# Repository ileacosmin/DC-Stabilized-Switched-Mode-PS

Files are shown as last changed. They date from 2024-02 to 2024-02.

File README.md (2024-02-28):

# DC Stabilized Switched Mode Power Supply

## Description
This project involves the design and implementation of a switched-mode power supply (SMPS) aimed at stabilizing a DC output voltage. The system utilizes a transformer, a full-wave rectifier, and a buck converter controlled through the pulse-width modulation (PWM) method.

## Features
- Utilizes KiCad for designing the electrical schematic.
- Employs MATLAB for computing the controllers and simulating the performance against certain disturbances.
- Switched-mode operation for efficiency and stability.
- Pulse-width modulation (PWM) control for precise regulation of output voltage.
- Full-wave rectification for converting AC input to DC.

## Electrical Scheme
schema electrica_page-0001

<!-- Insert snippet of the electrical schematic here -->

## Design Process
1. **Schematic Design**: Utilize KiCad to design the electrical schematic, including components such as the transformer, rectifier, and buck converter.
2. **Controller Design**: Use MATLAB to compute the controllers required for stable operation of the buck converter. This includes determining the PWM signals for regulating the output voltage.
3. **Simulation**: Simulate the performance of the SMPS against various disturbances using MATLAB to ensure stability, efficiency, and proper regulation of the output voltage.
4. **Implementation**: Fabricate the designed circuit and implement the controllers to create the physical SMPS.

## Conclusion
The DC stabilized switched-mode power supply provides a reliable and efficient solution for stabilizing DC output voltage. By leveraging KiCad for schematic design and MATLAB for controller computation and simulation, the project ensures optimal performance and stability under varying operating conditions.

## References
- [KiCad](https://kicad-pcb.org/)
- [MATLAB](https://www.mathworks.com/products/matlab.html)

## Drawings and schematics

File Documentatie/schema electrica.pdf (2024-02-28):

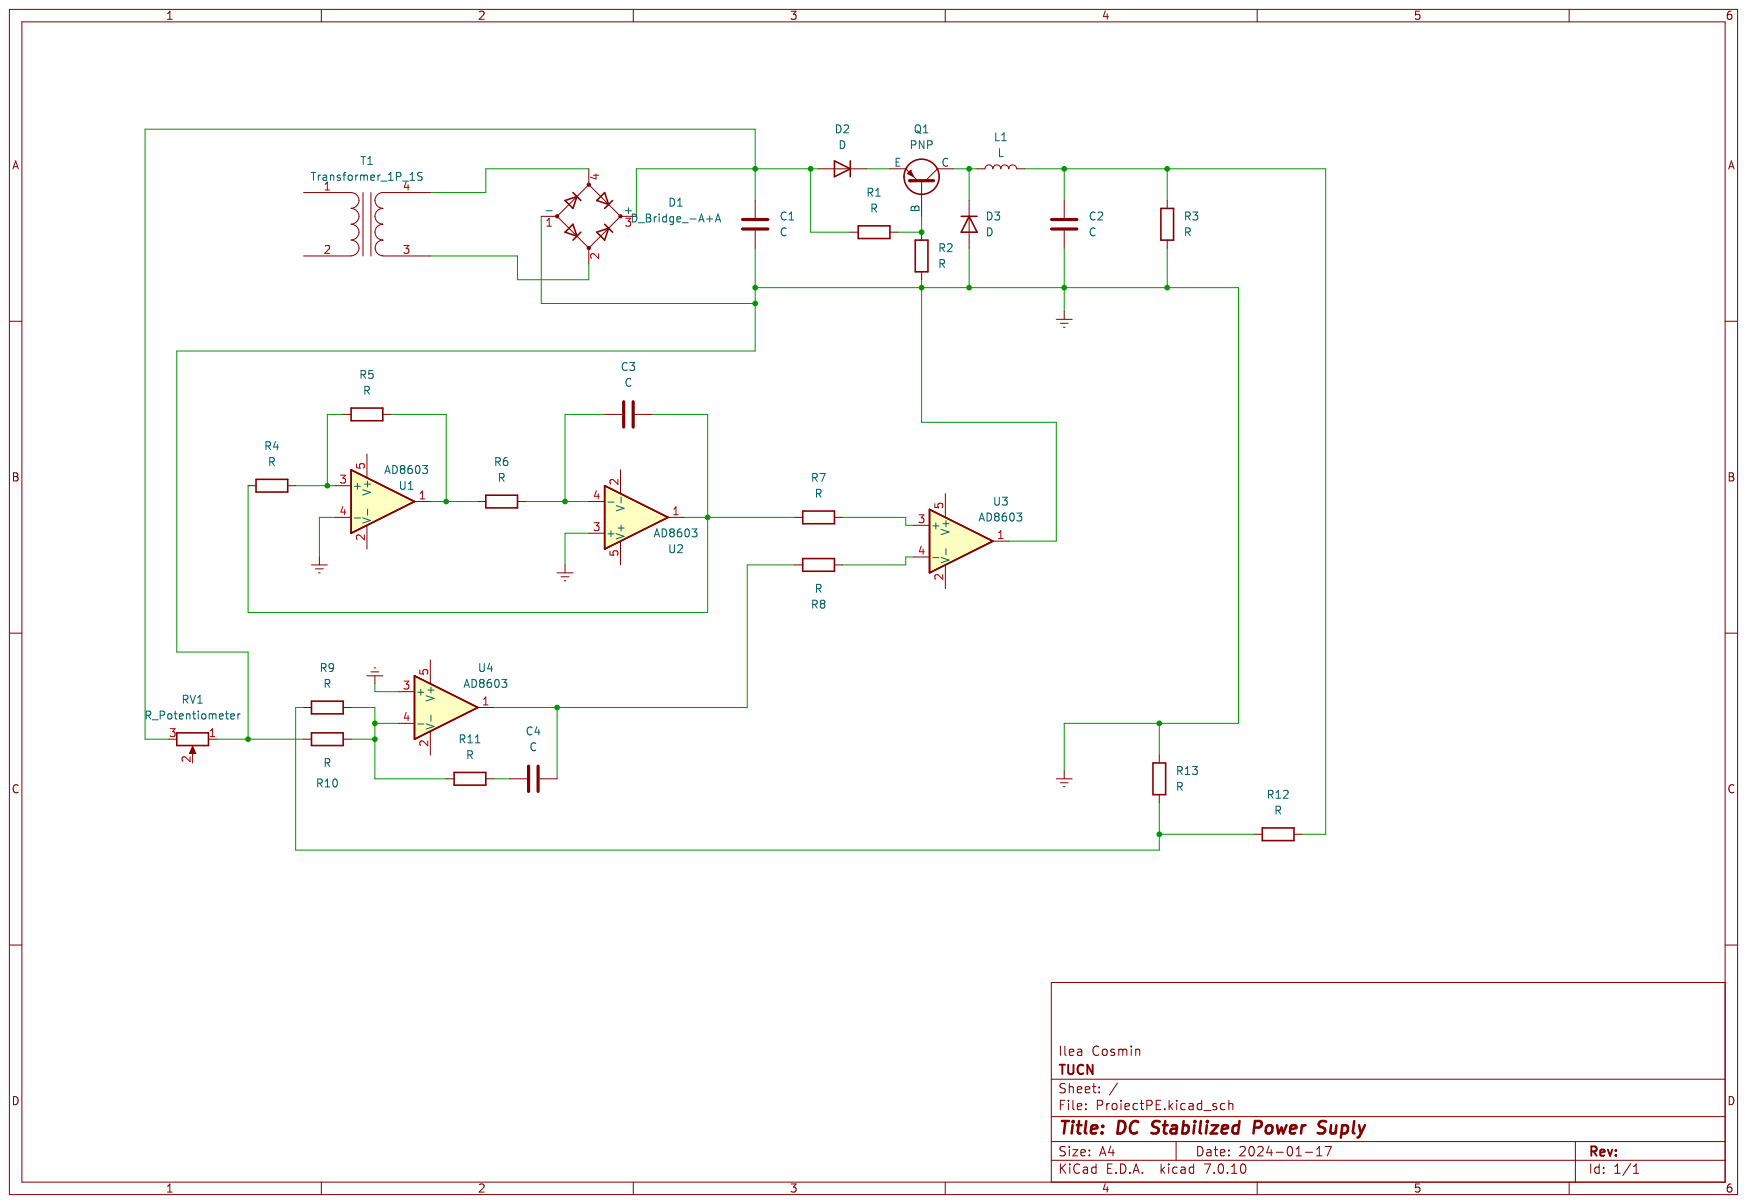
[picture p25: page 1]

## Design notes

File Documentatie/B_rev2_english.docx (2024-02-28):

B. DESIGN OF CONTROLLED DC power supplies

In section (A) was designed one unstabilized DC power supply using smoothing capacitor as presented in figure 6:

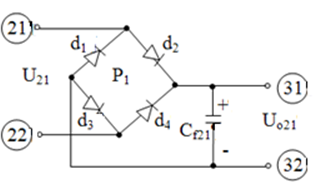
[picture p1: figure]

Figure 6. Uncontrolled rectifier, unstabilized

The voltage at the terminals (31, 32) is monopolar (+ 31, - 32).

B1. Design of a Step-Down (BUCK) DC power supply using the unstabilized power supply (UO21)

The design of switching mode, stabilized DC power supply (SMPS) cconsists of two steps:

a) The design of a DC- DC Converter which controls the output voltage ( U_(Ost) ), containing a “power” circuit and a duty cycle (µ) control circuit. The DC-DC converter plays the role of an actuator.
b) The design of an appropriate controller able to fulfill certain imposed performance specifications.

The conventional structures for DC-DC step-down converter are given in figure B1.

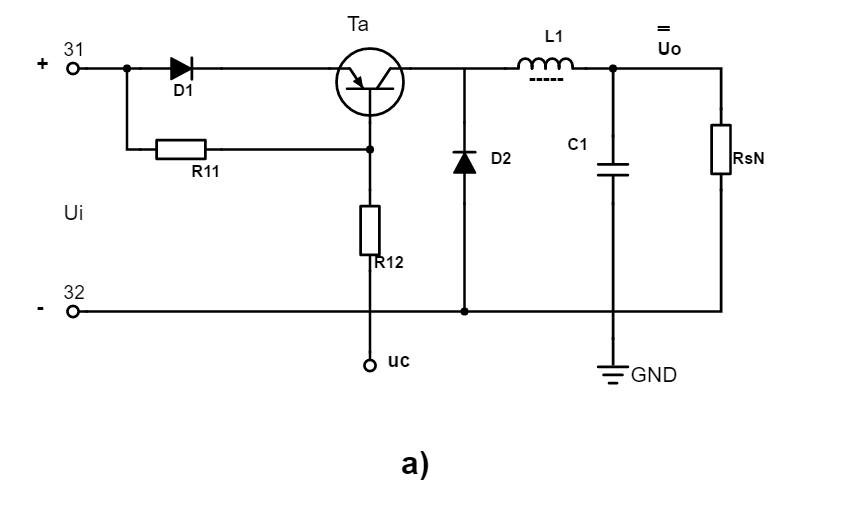
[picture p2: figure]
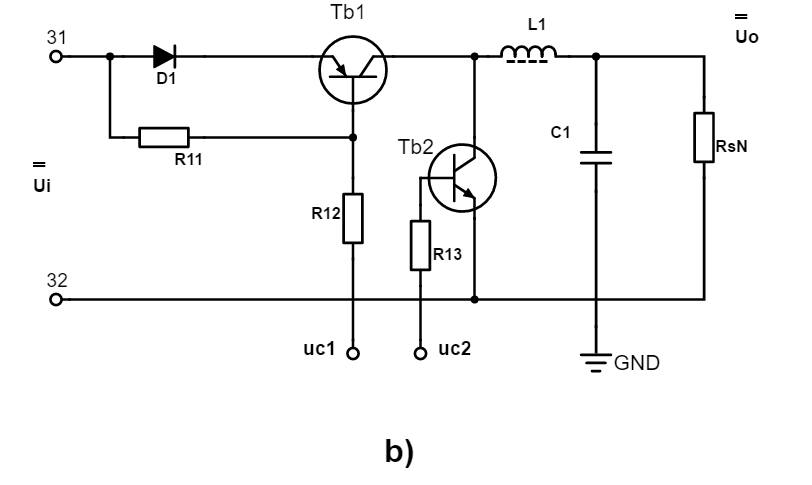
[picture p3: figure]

Figure B1. Switched model step-down DC-DC converter: a) with diode; b) with tranzistors

B1a. Design of the step-down DC-DC converter

A series of initial data are imposed for the design:

1) µ=µo=0.5=constant
2) Nominal load resistor

R_(SN) =(U_2)/(I_2)[Ω]

For which ( U_(2i) , I_(2i) ) are given as initial data for the project.

3) Supply voltage (Ui)

U =k_u ∙E_2 =k_u ∙√2∙U_(2i) [V]

where (ku) is the no load working regime voltage coefficient (A.3.2.3)

4) Maximum supply voltage

(U )_(max) =√2∙U_2

5) Nominal output voltage

V_o =μ_o ∙U ==0,5∙U [V]

6) Nominal load current:

(I_o )_N =(V_o)/(R_S)[A]

7) The current variation limit through the filtering coil:

∆I_L ≅(0,20÷0,30)(I_o )_N [A]

8) The voltage variation limit ( ∆V_O ) due to the alternative component (ripple voltage)

∆V_O ≅(2÷5)%∙V_o [V]

9) Swithching frequency

fc=20[kHz]

Using the presented initial data the elements of the DC-DC converter must be chosen:

1. Knowing that

∆I_L ≅(((U )_(max) -V_o )∙μ_o)/(f_c ∙L)

with ∆I_L ≅(0,20÷0,30)(I_o )_N =(0,20÷0,30)(V_o)/(R_S)

will give the minimum necesarry value of the filtering coil (L):

L≥(((U )_(max) -V_o )∙μ_o)/(f_c ∙∆I_L)[H]

2. Knowing the AC component equilibrium ( ∆I_L , ∆V_O ) results:

∆V_O ≅∆I_L ∙(t_(ON))/C=∆I_L ∙(μ_o ∙T_C)/C=∆I_L ∙(μ_o)/(f_C ∙C)

which gives:

C=(∆I_L ∙μ_o)/(f_C ∙∆V_O)=(0,5∙∆I_L)/(f_C ∙∆V_O)

For the solution presented in figure B1a, the diode (d2) is a Shottky diode which must handle:

- Reverse voltage : U_A ≥1,25∙(U )_(max)
- Rectified current: I_A ≥1,5∙(I_o )_N

considering a safety coefficient of (1,25) for voltage and (1,5) for current.

Diode (d1) is a low frequency diode (rectifier diode) which has to handle the current (IA) previously computed.

Tranzistors (Ta), (Tb1) and (Tb2) for switching frequencies up to 20 (kHz) may be:

- Bipolar tranzistors
- MOSFET tranzistors
- IGBT tranzistors

and must handle:

- A load voltage: U_(tranzistor) =2∙√2∙U_21
- A load current: I_(tranzistor) =1,5∙(I_o )_N

The resistors (R12, R13) can be chosen considering the appropriate control current.

B1b. Design of the control circuit for the step-down DC-DC converter

The structure given in figure 7 corespunde unei prime variante

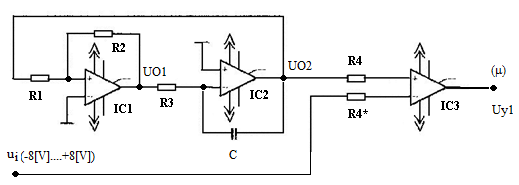
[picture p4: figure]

Figure 7. The structure of the PWM modulator (version)

The operational amplifier (IC1) is used as a Schmidt Trigger and the operational amplifier (IC2) is used as an integrator. (IC3) operational amplifier, with no feedback, is used as a comparator. The considered supply is of (+/- 16 V). In order to generate the triangular wave voltage (UO2) with the amplitude of (A=8V) is necessary that R2=2∙R1. By choosing R2=20[kΩ], will result that R1=10[kΩ].

The switching frequency is given by the following relationship:

f_c =1/(2∙R_3 ∙C)=>R3=0,00021 [Ω]

By choosing at first the capacitor value (C), at an imposed value of the switching frequency, can be computed the value of resistor R3. The comparator (IC3) will generate a rectangular bipolar wave with an amplitude of 16[V], with a duty cycle (μ), controlled by the voltage (ui) and which can be computed by:

μ=(u_i +8)/(2∙A)

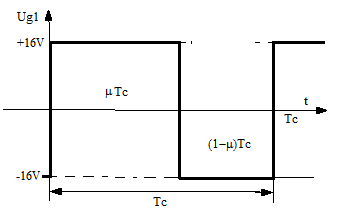
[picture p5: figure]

Figure 8. The evolution of the PWM voltage

The static characteristic of the PWM modulator is given in figure 8.

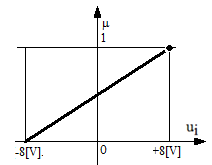
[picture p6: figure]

Figure 9. The variation of the duty cycle (μ)

In the following design steps, the PWM modulator can be considered as an amplification element with an amplification factor of:

K=(∆μ)/(∆u_i)=1/(2A)

The voltage (ui), figure 7 is generated by the controller attached to the circuit.

Observations:

1. The conventional structure of the PWM modulator presented in figure 7 implies a fairly complex practical implementation, beeing the reason why other versions of PWM modulator can be considered and tested.
2. PWM modulator using LM324 integrated circuit (description in Anexa B1)
3. It is recommended to chose a integrated circuit to implement the PWM modulator and include the structure description, the operating mode and application.

Examples of dedicated integrated circuits:

a) TL 494/ TL 594 ("Texas Instruments”)
b) MAX 666 (“Maxim”)
c) LTC 6992-1 (“Linear Technology”)

B1c. The step- down DC-DC converter mathematical model

The structure of the stabilized DC power supply is based on the fixed part presented in figure 10.

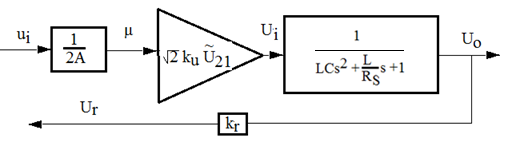
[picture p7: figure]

Figure 10. The fixed part of the switched mode stabilized DC power supply

A resistive voltage divider is considered on the feedback with a factor of kr=0,2.

The reference value of the DC power supply wil be V_0^(*) =μ_0 ∙k_r ∙U_i .

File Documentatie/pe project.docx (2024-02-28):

Technical University of Cluj-Napoca

Faculty of Automation and Computer Science

Project:

DC STABILIZED SWITCHED MODE POWER SUPPLY

C.

The Controllers design

2023-2024

C.1. Controller design

For the project we had to use two different kinds of controllers:

- Proportional
- Proportional-Integral

The transfer function of the fixed part:

H_f (s)=1/(2A)∙√2∙k_u ∙U_2 ∙1/(LCs^2 +L/(R_s)s+1) = 0.6894/(6.49∙10^(-7) ∙s^2 + 0.002596 s + 1)

C.1.1 Proportional Controller Design

Because H_f has two real negative a P controller will not ensure a steady state error ε_(ss) =0 .

We will impose the following performance characteristic for the overshoot σ:

σ=10%

We can use the root locus of the fixed transfer function to tune our controller:

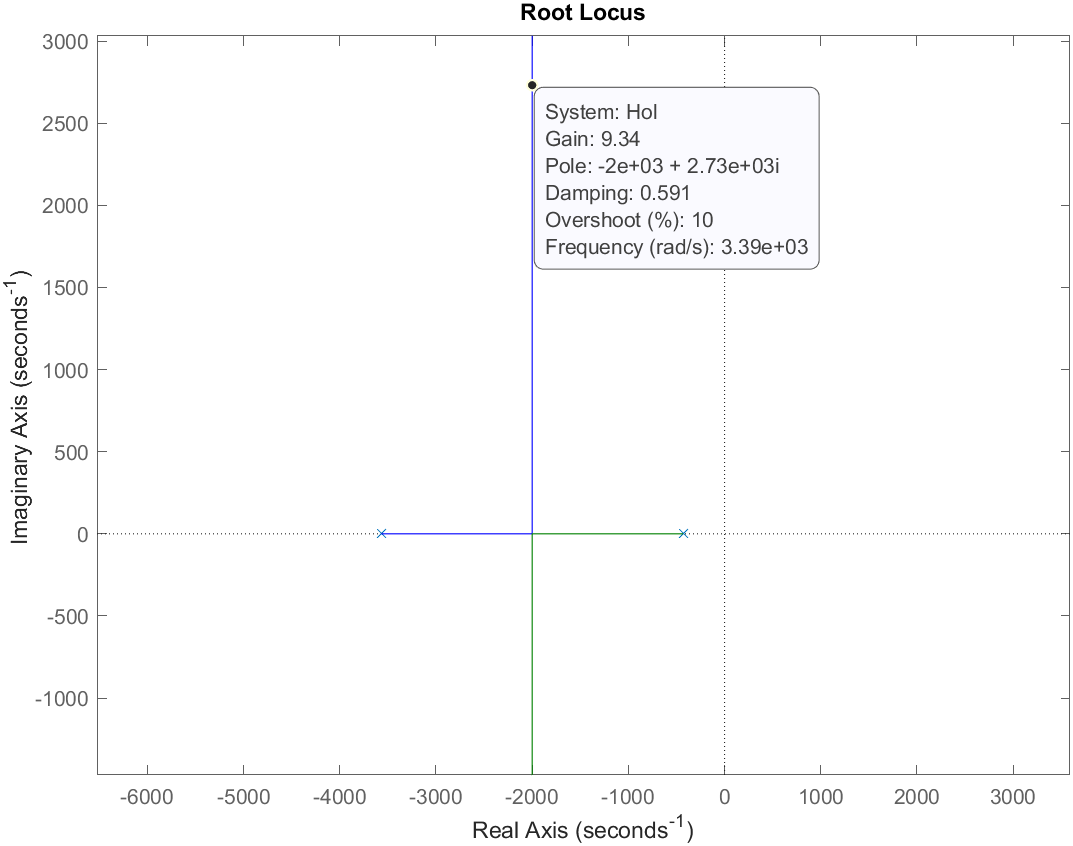
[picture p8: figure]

Therefore the value for kp=9.34

C.1.2 Proportional-Integral Controller Design

We will impose the following performance characteristic for the overshoot σ:

σ=10%

The controller transfer function will be:

H_c (s)=k_p ∙(1+T_i ∙s)/(T_i ∙s)

We will take T_i =1/432 witch is the dominant time constant in our process and we will cancel it.

We can again use the root locus of the fixed transfer function to tune our controller:

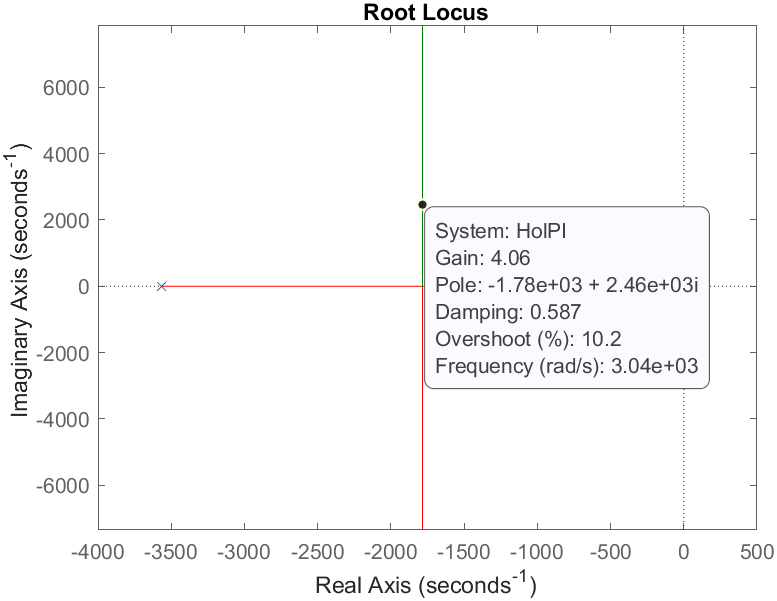
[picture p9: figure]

Therefore the value for kp=4.06 and T_i =1/432 .

Technical University of Cluj-Napoca

Faculty of Automation and Computer Science

Project:

DC STABILIZED SWITCHED MODE POWER SUPPLY

D.

The simulation of the stabilized DC power supply

2023-2024

D.1. Step response

D.1.1 Step response on the P controller:

We have the following simplified mathematical model of the DC power supply:

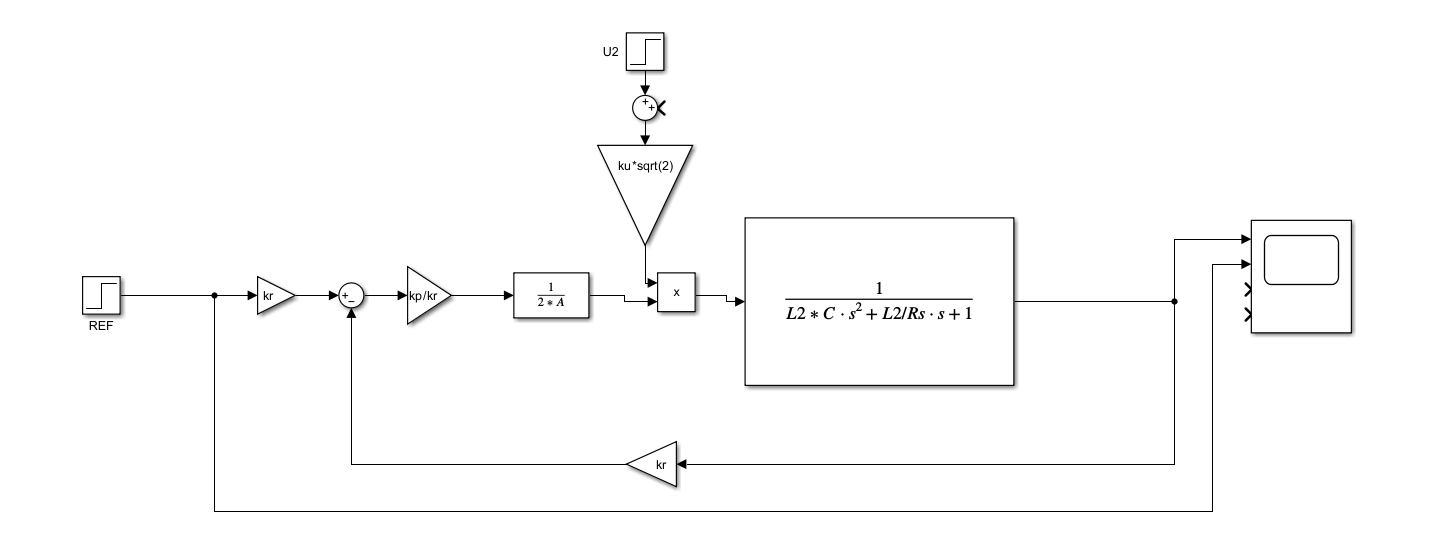
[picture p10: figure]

The reference will be: V_0^(*) =11.03V thus giving the following simulation:

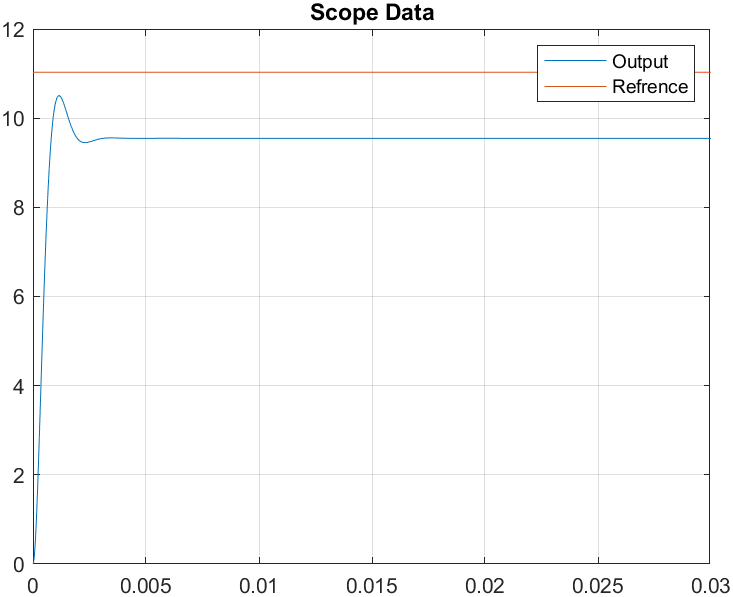
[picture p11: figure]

The output has an overshoot of: σ=10% and a steady state error of: ε_(ssp) =15,71% .

D.1.2 Step response on the PI controller:

The simplified mathematical model of the DC power supply is:

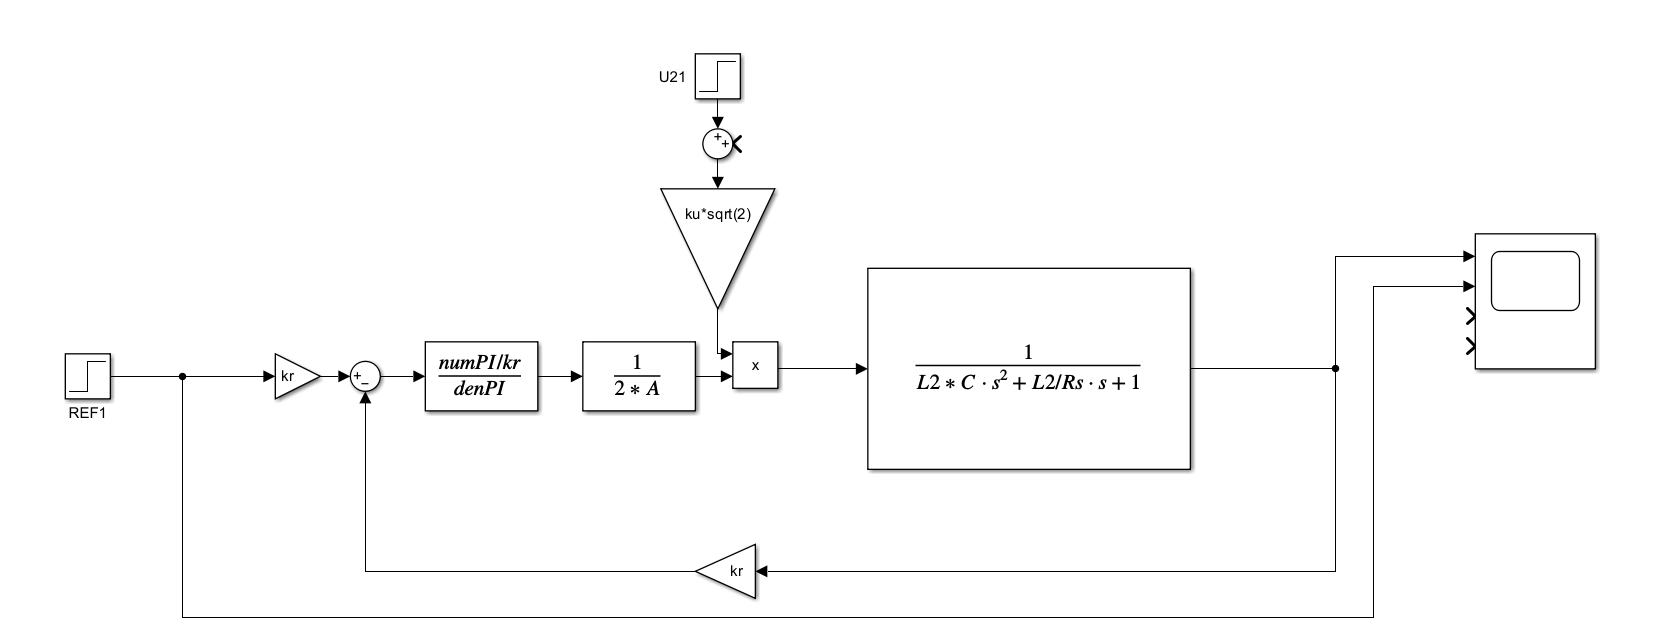
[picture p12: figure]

With the same reference voltage as before we have the following response:

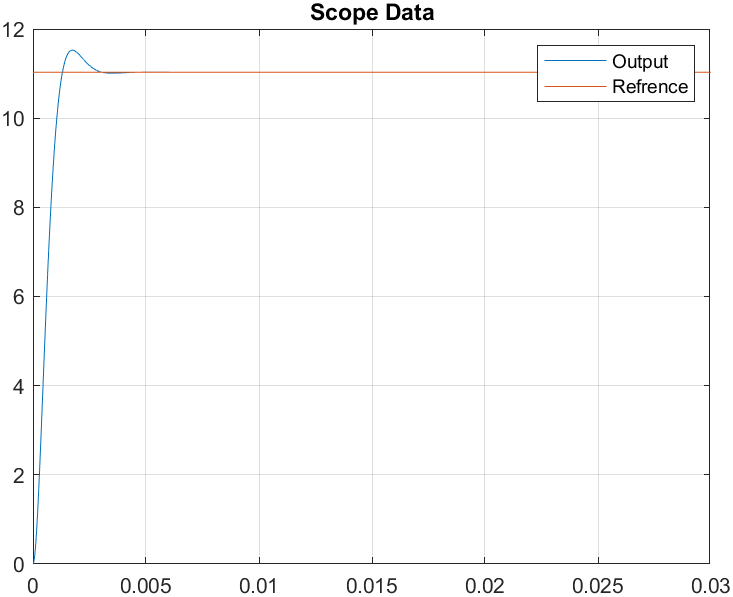
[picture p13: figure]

We see that the overshoot is no more than σ=10% and the steady state error ε_(ssp) =0 .

D.2. Step response with disturbance to the input

D.2.1 Input disturbance on the P controller:

I added a perturbation of 10%∙U2 [V] at the moment in time 0.005 seconds.

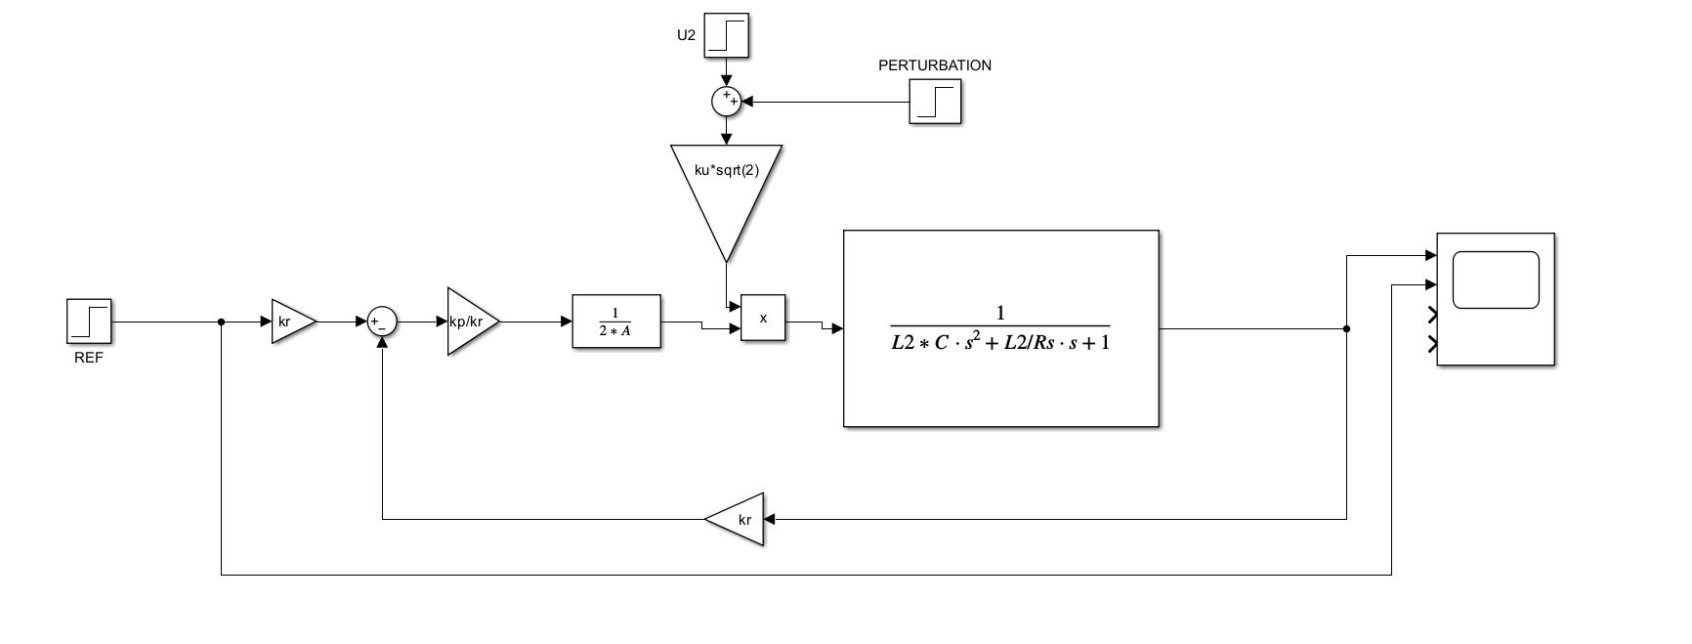
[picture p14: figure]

And this is the result of the simulation:

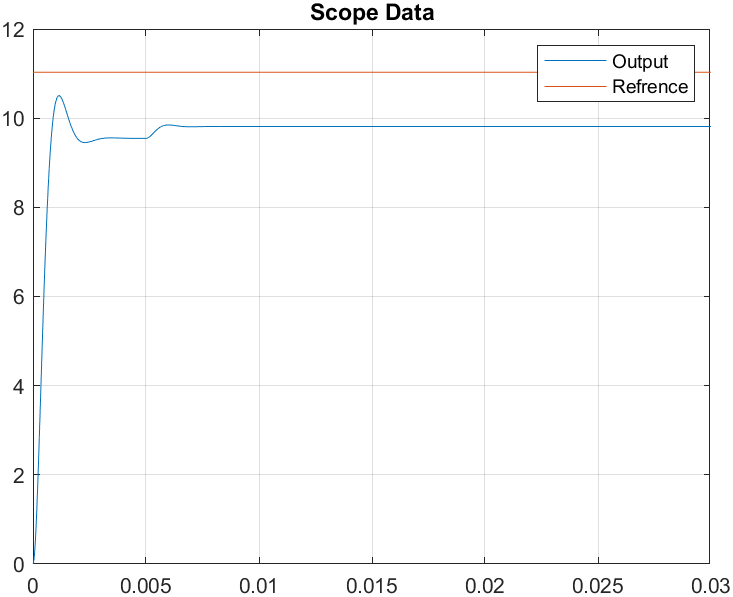
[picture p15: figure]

D.2.2 Input disturbance on the PI controller:

I added a perturbation of -10%∙U2 [V] at the moment in time 0.015 seconds.

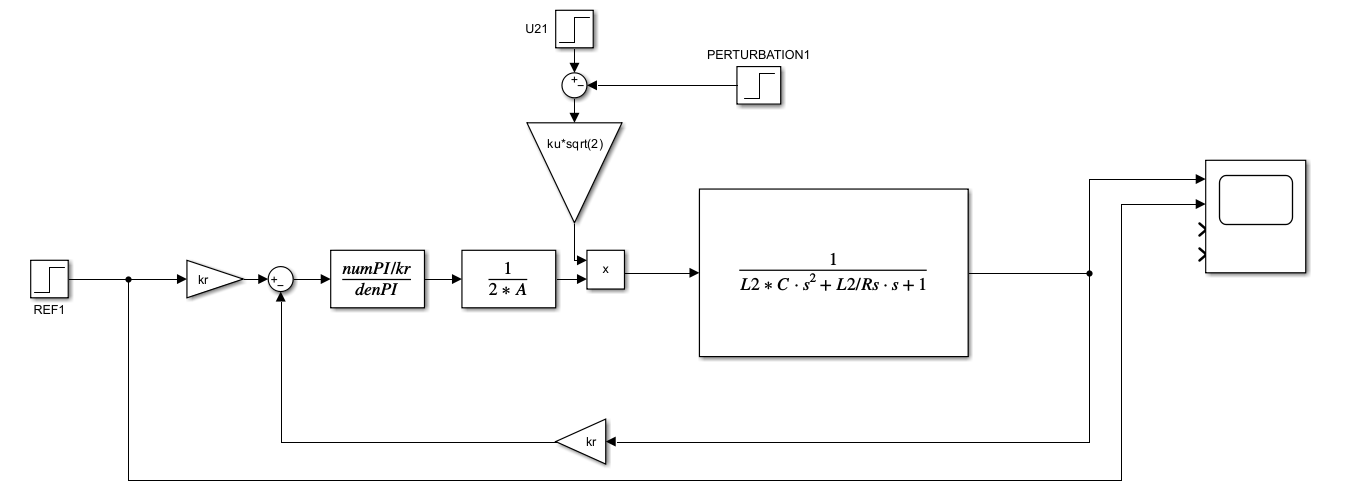
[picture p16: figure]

And this is the result of the simulation:

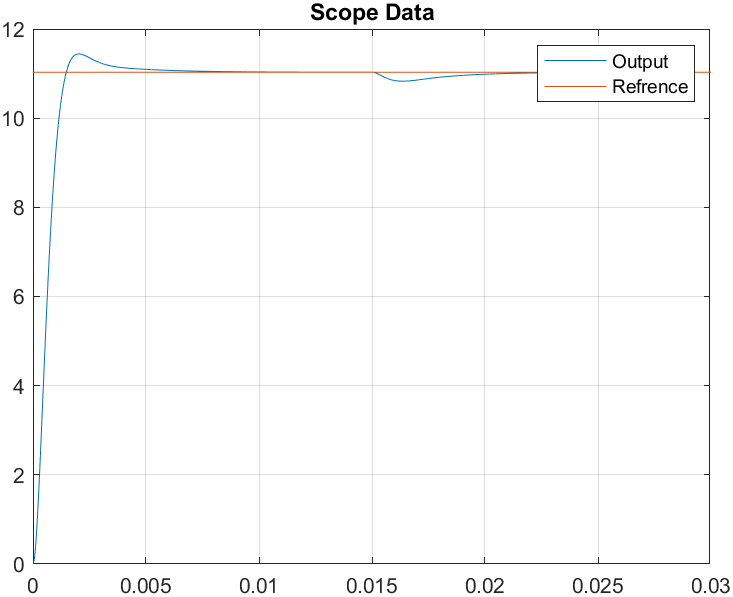
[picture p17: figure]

D.3. Step response with disturbance to the output

D.3.1 Output disturbance on the P controller:

I added a perturbation of -20%∙Rs at the moment in time 0.012 seconds.

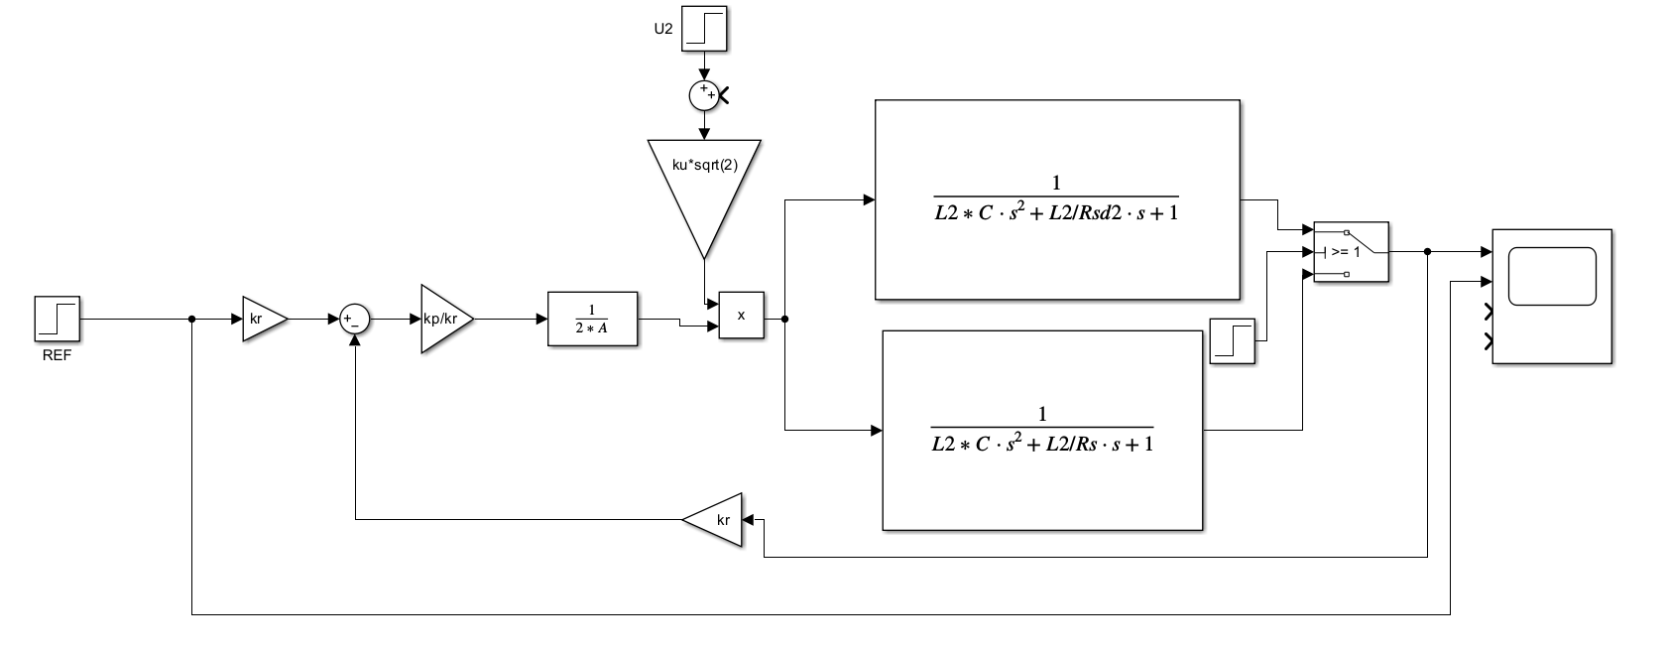
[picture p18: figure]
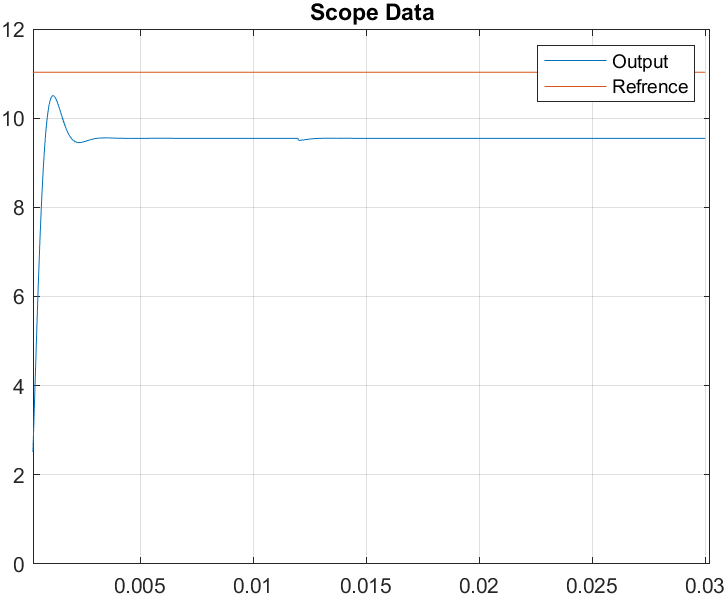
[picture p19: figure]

D.3.2 Output disturbance on the PI controller:

I added a perturbation of -20%∙Rs at the moment in time 0.012 seconds.

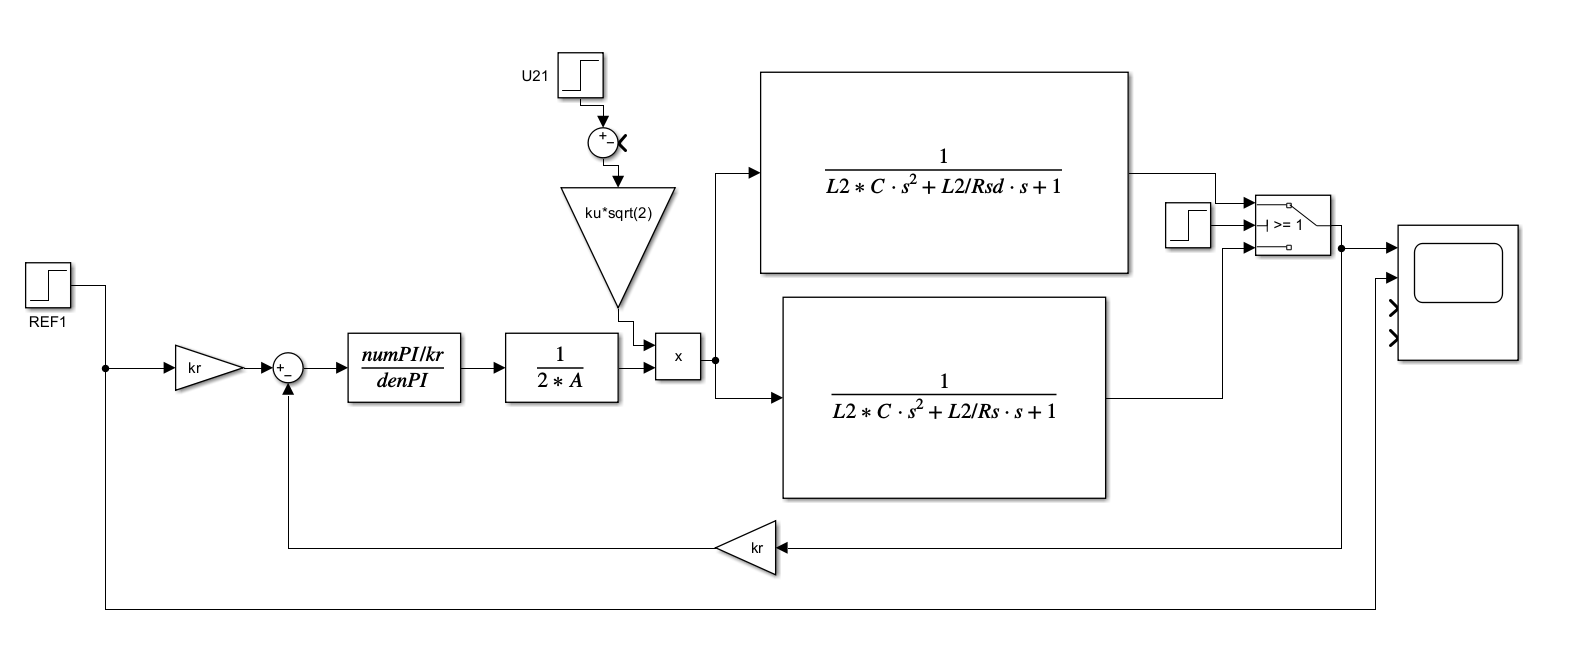
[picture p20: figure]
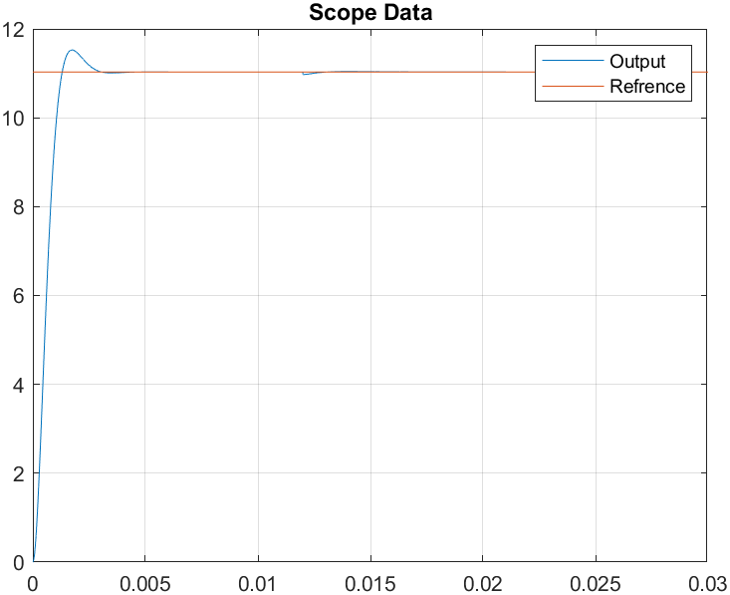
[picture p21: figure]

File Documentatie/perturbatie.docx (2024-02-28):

D.3.1/2 Output disturbance on the P controller (compared):

Used the same disturbance characteristics as in 3.1 but now we see the compared responses.

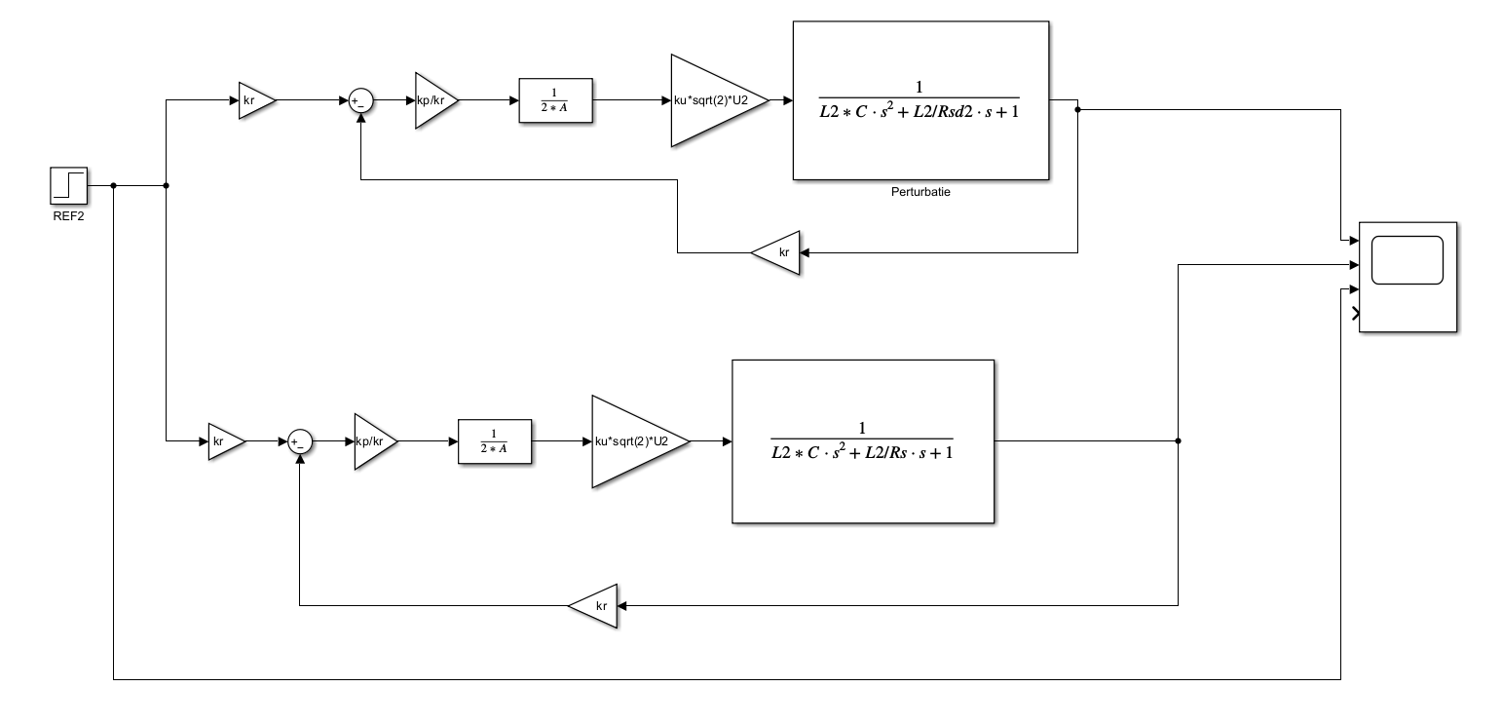
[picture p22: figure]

The P controller shows a lower overshoot.

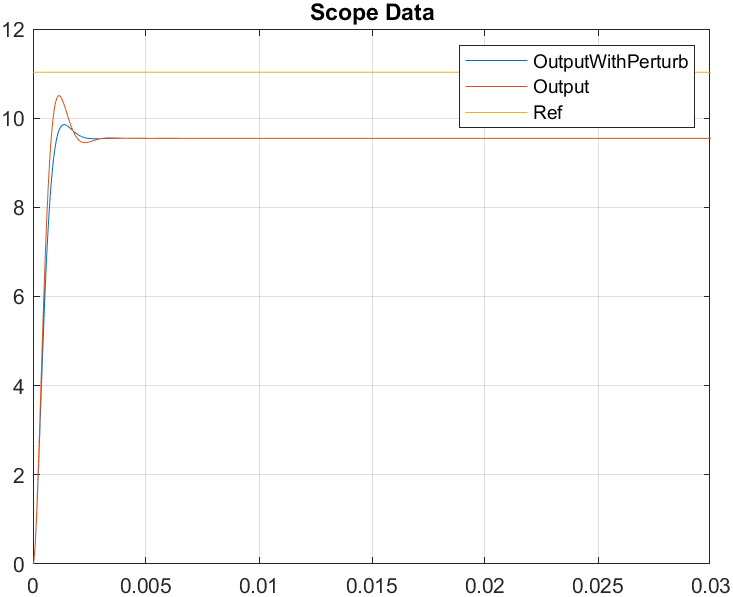
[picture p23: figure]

D.3.2/2 Output disturbance on the PI controller (compared):

Used the same disturbance characteristics as in 3.2 but now we see the compared responses.

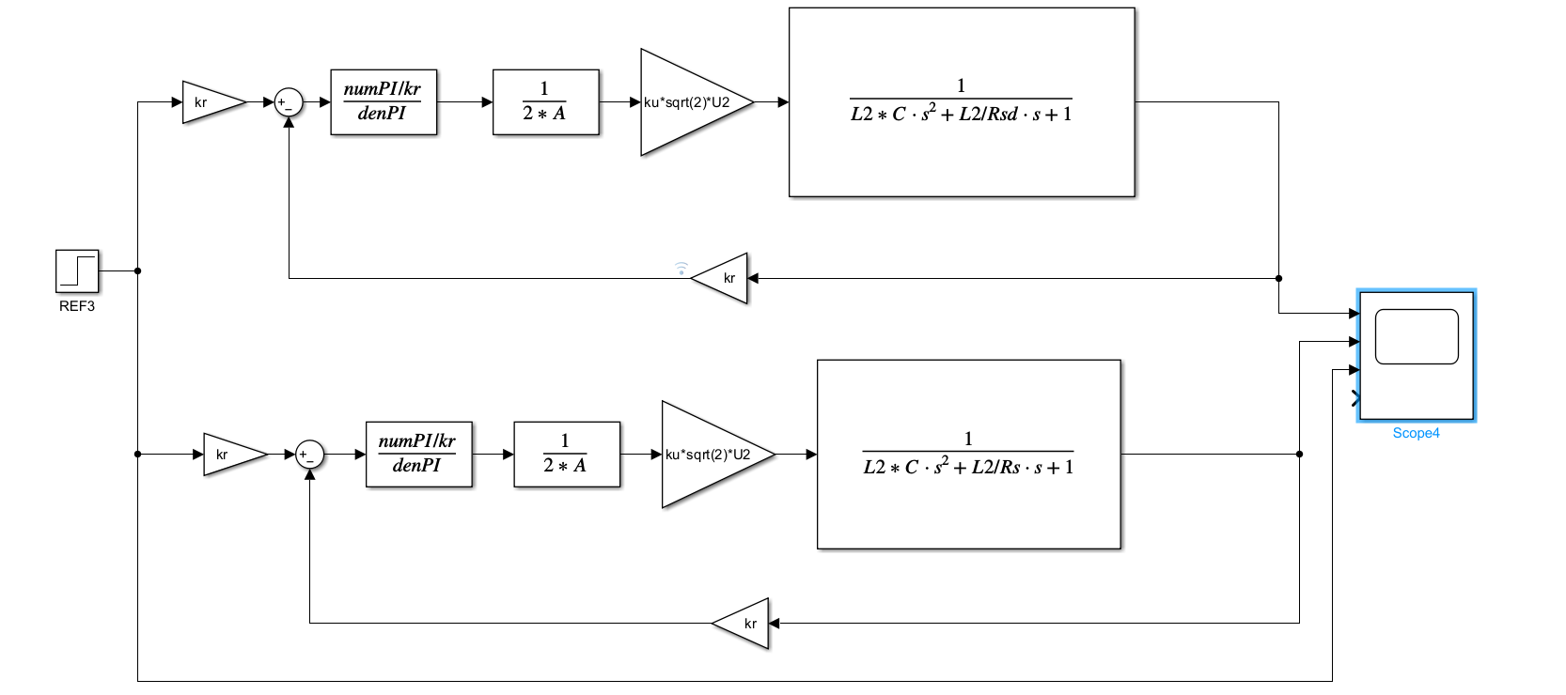
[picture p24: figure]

The PI controller gives us a longer settling time.
